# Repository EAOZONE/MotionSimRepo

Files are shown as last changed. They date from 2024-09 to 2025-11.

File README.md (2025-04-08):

# Project Description
This python project is an automation tool to control some hardware with your computer. It uses the `PySide6` library for a graphical user interface (GUI) and the `serial` library to communicate with an Arduino controller which manages the hardware. The CSV file containing required details is read using `Pandas`, a powerful library for data analysis in Python.
## Module Descriptions
The project is split into three different files:
1. **widget.py**: This file is the main application, it creates a GUI using PySide6 which allows user to interact with the application. The GUI comprises of elements including buttons, checkboxes, sliders etc. It leverages `ArdiunoTalk` and `saveFileAsArr` classes to communicate with Arduino and manipulate data respectively. It also includes keyboard event to trigger function via key press.
2. **talkToArduino.py**: This file includes class `ArdiunoTalk` which establishes communication with Arduino and sends angles by writing to serial. It also includes functionality to enable/disable the Arduino operation.
3. **readCSV.py**: This file contains a function to read a CSV file and return its contents as a list of tuples. It uses pandas library to accomplish this.

## Setup & Usage
You can run the project simply by running the `widget.py` file in a python environment that has the `PySide6`, `Pandas`, and `serial` libraries installed. This opens a graphical user interface which can be used to interact with the connected Arduino.
This application assumes that the Arduino is connected to the computer and there exists a CSV file named `test.csv` in the same directory containing the required information in the format needed.
## Functionality
Once enabled by checking the `Enable All` checkbox on the UI, you can then interact with:
- Home button to set all angles to 0.
- The three dials to manually adjust angles.
- A list of predefined named buttons that represent specific sequences of angles, which are read from a CSV file.
- An `E-Stop` button can be used to discontinue execution of any ongoing command.
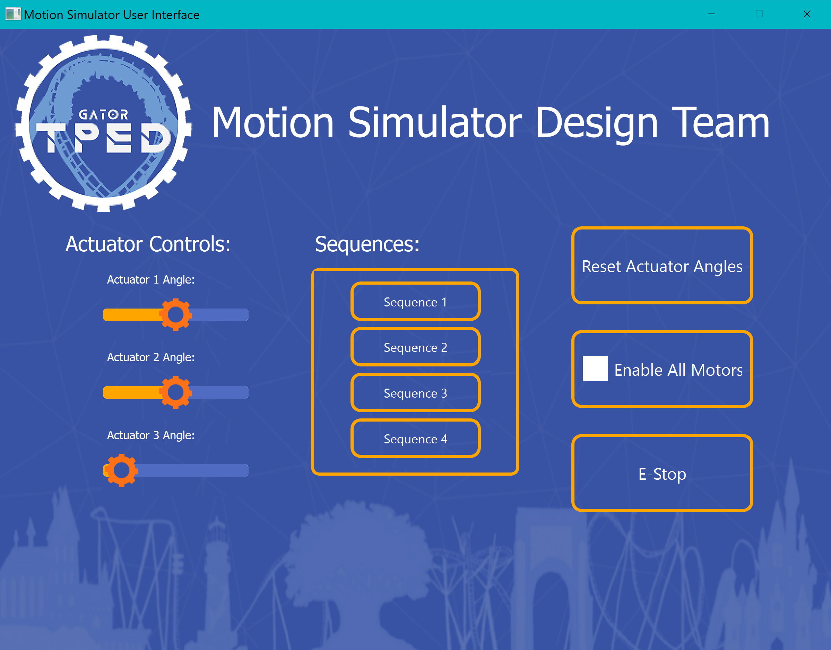
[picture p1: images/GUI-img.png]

This is a very flexible codebase and can be edited according to your individual needs. For further queries & understanding about the code, kindly delve into the files.

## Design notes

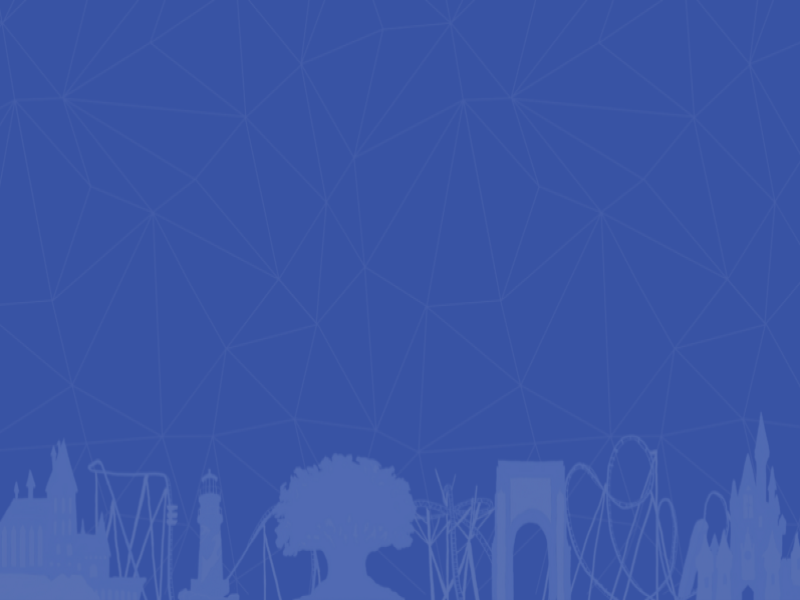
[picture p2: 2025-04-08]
images/background.png

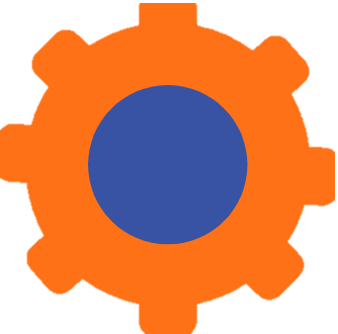
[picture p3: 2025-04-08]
images/gear.png

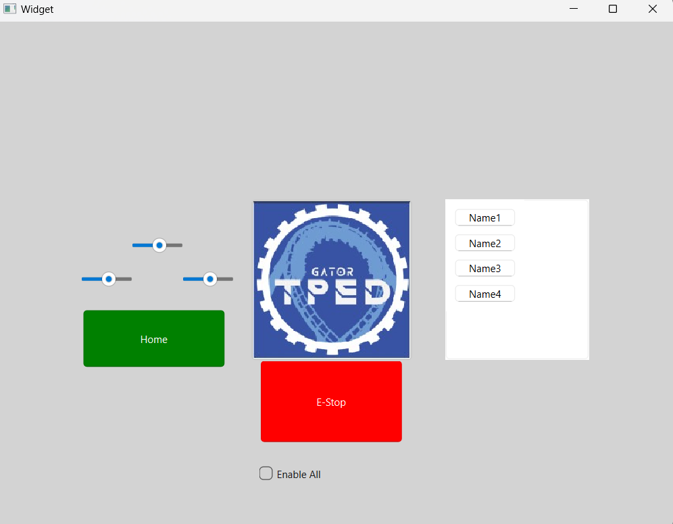
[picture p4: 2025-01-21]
images/img.png

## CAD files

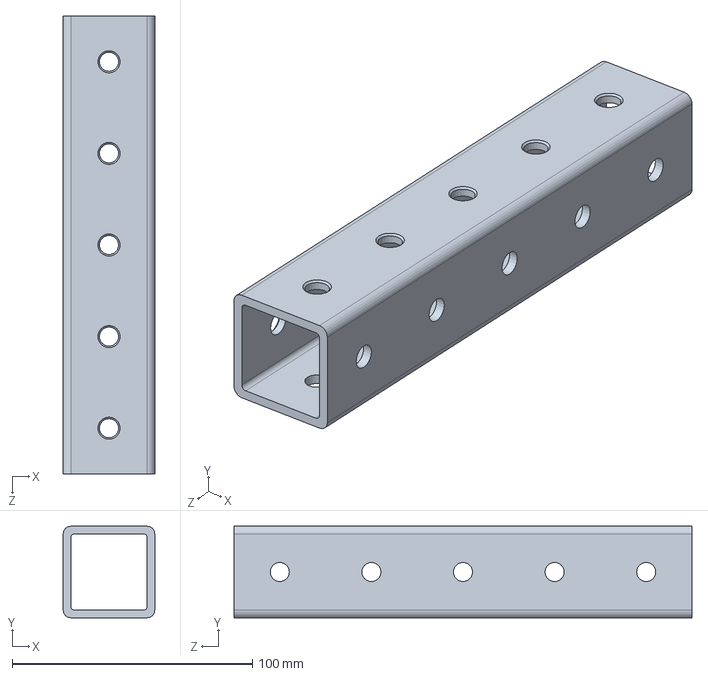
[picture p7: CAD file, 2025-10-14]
SOLIDWORKS/midassembly (1)/9701-7_5-CL.SLDPRT
38.1 x 38.1 x 190.5 mm

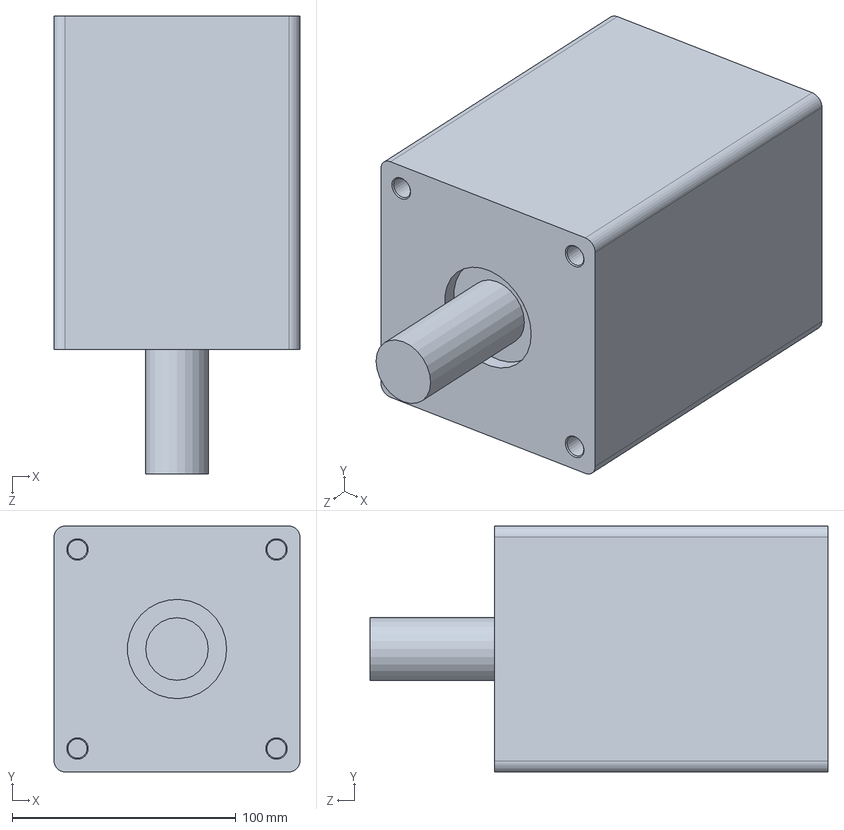
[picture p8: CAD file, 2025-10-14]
SOLIDWORKS/midassembly (1)/Nema 42.SLDPRT
110.0 x 110.0 x 204.6 mm

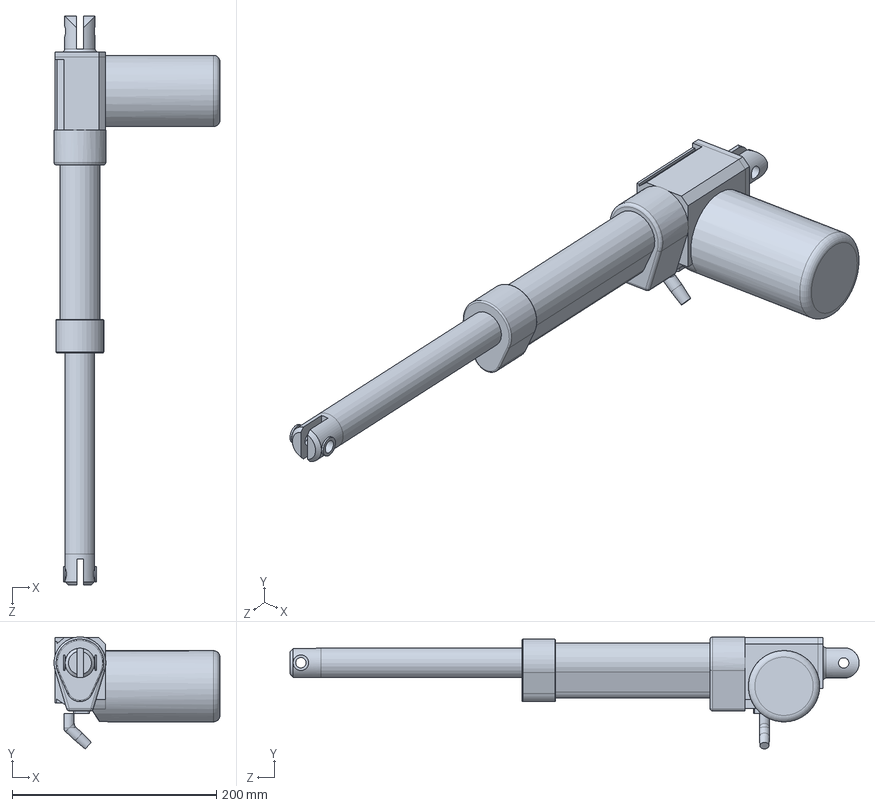
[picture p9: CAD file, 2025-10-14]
SOLIDWORKS/midassembly (1)/PA-04 (4).SLDPRT
162.6 x 109.6 x 557.2 mm

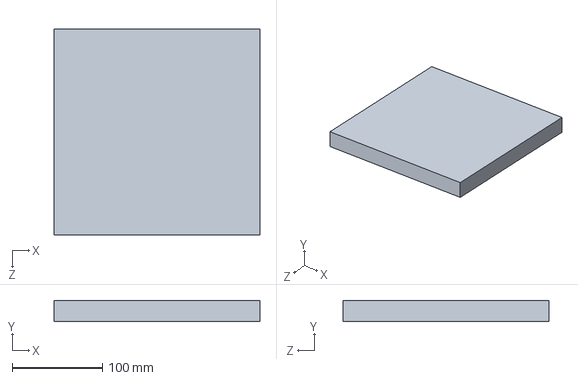
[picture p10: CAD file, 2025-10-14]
SOLIDWORKS/midassembly (1)/wood spacer.SLDPRT
228.6 x 23.6 x 228.6 mm

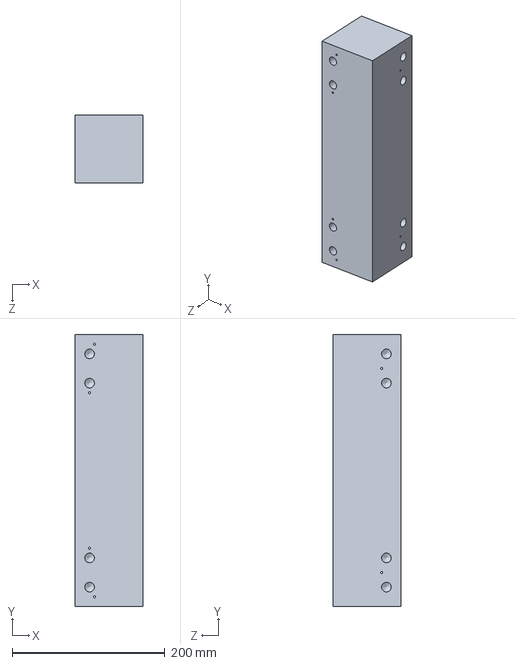
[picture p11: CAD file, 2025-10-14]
SOLIDWORKS/midassembly (1)/2by4legB.SLDPRT
88.9 x 355.6 x 88.9 mm

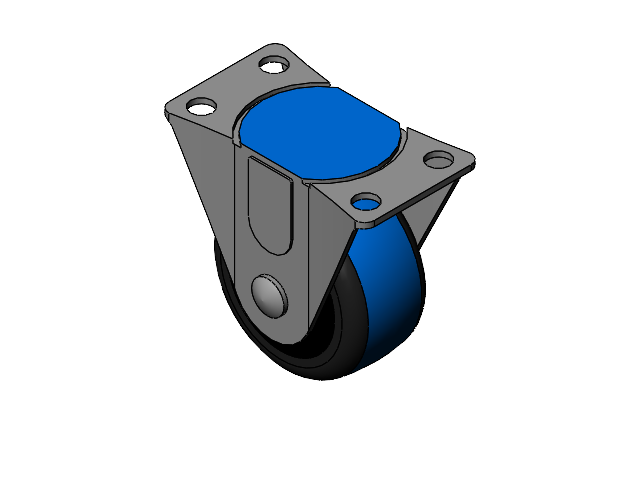
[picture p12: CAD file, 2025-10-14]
SOLIDWORKS/midassembly (1)/30POP20R.sldasm
100-20R_R
21.25-A
21-2x1-T
21-2x1-C

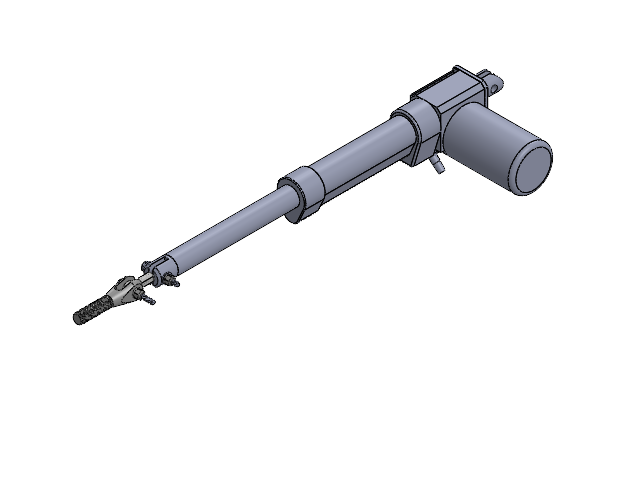
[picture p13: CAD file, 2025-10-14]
SOLIDWORKS/midassembly (1)/ActuatorAssembly.SLDASM
PA-04 (4)
2440K51_High-Strength Fully Threaded Rod End Bolt
2458K321_Lubrication-Free Ball Joint Rod End
90945A760_18-8 Stainless Steel Mil. Spec. Washer x 5
4749T191_Externally Threaded Clevis Rod End
92320A622_18-8 Stainless Steel Unthreaded Spacer x 2
91268A109_High-Strength Grade 8 Steel Hex Head Screw x 2
90630A110_High-Strength Steel Nylon-Insert Locknut (1) x 2
92871A083_18-8 Stainless Steel Unthreaded Spacer x 2

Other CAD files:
SOLIDWORKS/midassembly (1)/Table Top Gear 1.SLDASM
SOLIDWORKS/midassembly (1)/Table Top Gear_ThickTest2.SLDASM
SOLIDWORKS/midassembly (1)/Turntable Gear.SLDASM
SOLIDWORKS/midassembly (1)/Gear.SLDASM
SOLIDWORKS/midassembly (1)/Table Top Gear.SLDASM
SOLIDWORKS/midassembly (1)/Drive Gear 1.SLDASM
SOLIDWORKS/midassembly (1)/Drive Gear.SLDASM
SOLIDWORKS/midassembly (1)/Table Top Gear_ThickTest.SLDASM
SOLIDWORKS/midassembly (1)/Drive Gear_ThickTest.SLDASM
SOLIDWORKS/midassembly (1)/21-2x1-T.sldprt
SOLIDWORKS/midassembly (1)/21-2x1-C.sldprt
SOLIDWORKS/Gear.SLDASM
SOLIDWORKS/Turntable Gear.SLDASM
SOLIDWORKS/midassembly (1)/100-20R_R.sldprt
SOLIDWORKS/midassembly (1)/1544T12_Lubricated Turntable.SLDPRT
SOLIDWORKS/midassembly (1)/21.25-A.sldprt
SOLIDWORKS/midassembly (1)/2440K51_High-Strength Fully Threaded Rod End Bolt.SLDPRT
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

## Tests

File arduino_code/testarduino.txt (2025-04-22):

// Motor control pins
const int enPin  = 8;   // MegaMoto ENABLE pin
const int pwmA   = 9;   // MegaMoto PWMA (forward / extend)
const int pwmB   = 10;  // MegaMoto PWMB (reverse / retract)

// Hall effect sensor pin
const int hallPin = 2;  // Must be an interrupt-capable pin on your Arduino

// Timing and speed parameters
const int extendTime = 5000;  // milliseconds
const int retractTime = 5000;
const int speed = 200;        // PWM duty cycle (0–255)

// Pulse count variable
volatile unsigned long pulseCount = 0;

void setup() {
  // Initialize motor control pins
  pinMode(enPin, OUTPUT);
  pinMode(pwmA, OUTPUT);
  pinMode(pwmB, OUTPUT);
  digitalWrite(enPin, HIGH); // Enable motor driver

  // Initialize hall effect sensor pin
  pinMode(hallPin, INPUT_PULLUP); // Use internal pull-up resistor
  attachInterrupt(digitalPinToInterrupt(hallPin), countPulse, RISING); // Trigger on rising edge

  // Initialize serial communication
  Serial.begin(9600);
}

void loop() {
  // Reset pulse count
  pulseCount = 0;

  // Retract actuator
  analogWrite(pwmA, 0);
  analogWrite(pwmB, speed);
  delay(retractTime);
  analogWrite(pwmB, 0); // Stop motor

  // Output pulse count after retraction
  Serial.print("Retract pulses: ");
  Serial.println(pulseCount);

  delay(1000); // Pause before next movement

  // Reset pulse count
  pulseCount = 0;

  // Extend actuator
  analogWrite(pwmA, speed);
  analogWrite(pwmB, 0);
  delay(extendTime);
  analogWrite(pwmA, 0); // Stop motor

  // Output pulse count after extension
  Serial.print("Extend pulses: ");
  Serial.println(pulseCount);

  delay(1000); // Pause before next cycle
}

// Interrupt Service Routine (ISR) for counting pulses
void countPulse() {
  pulseCount++;
}

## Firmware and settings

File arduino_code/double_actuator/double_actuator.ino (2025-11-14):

// ===================== USER-CONFIGURABLE CONSTANTS =====================
const float MAX_SPEED_IPS = 2.16;   // actuator speed in inches/second at full power
const float STROKE_IN     = 12.0;   // total stroke length in inches

// MegaMoto #1 (Actuator 1)
const int ENABLE1 = 8;
const int FWD1    = 11;   // PWM pin
const int REV1    = 3;    // PWM pin

// MegaMoto #2 (Actuator 2)
const int ENABLE2 = 7;
const int FWD2    = 10;   // PWM pin
const int REV2    = 5;    // PWM pin

// ===================== STATE VARIABLES =====================
float pos1_in = 0.0;  // estimated position of actuator 1 in inches (0 = fully retracted)
float pos2_in = 0.0;  // estimated position of actuator 2 in inches

// ===================== BASIC MOTOR CONTROL HELPERS =====================
void stopActuator1() {
  digitalWrite(ENABLE1, LOW);
  analogWrite(FWD1, 0);
  analogWrite(REV1, 0);
}

void stopActuator2() {
  digitalWrite(ENABLE2, LOW);
  analogWrite(FWD2, 0);
  analogWrite(REV2, 0);
}

void driveActuator1(int direction, int pwm) {
  // direction: +1 = extend (FWD), -1 = retract (REV), 0 = stop
  if (direction == 0 || pwm == 0) {
    stopActuator1();
    return;
  }

  digitalWrite(ENABLE1, HIGH);
  if (direction > 0) {
    // Extend
    analogWrite(REV1, 0);
    analogWrite(FWD1, pwm);
  } else {
    // Retract
    analogWrite(FWD1, 0);
    analogWrite(REV1, pwm);
  }
}

void driveActuator2(int direction, int pwm) {
  // direction: +1 = extend (FWD), -1 = retract (REV), 0 = stop
  if (direction == 0 || pwm == 0) {
    stopActuator2();
    return;
  }

  digitalWrite(ENABLE2, HIGH);
  if (direction > 0) {
    // Extend
    analogWrite(REV2, 0);
    analogWrite(FWD2, pwm);
  } else {
    // Retract
    analogWrite(FWD2, 0);
    analogWrite(REV2, pwm);
  }
}

// ===================== SETUP =====================
void setup() {
  pinMode(ENABLE1, OUTPUT);
  pinMode(FWD1, OUTPUT);
  pinMode(REV1, OUTPUT);

  pinMode(ENABLE2, OUTPUT);
  pinMode(FWD2, OUTPUT);
  pinMode(REV2, OUTPUT);

  stopActuator1();
  stopActuator2();

  Serial.begin(9600);
  Serial.println("System starting...");

  resetActuators();   // <<< run reset here

  Serial.println("Ready for serial commands: pos1,pos2,time");
}
void resetActuators() {
  Serial.println("Resetting actuators (full retract)…");

  // Full reverse, both actuators
  driveActuator1(-1, 255);   // direction -1 = retract
  driveActuator2(-1, 255);

  delay(7000);  // long enough to fully retract (adjust as needed)

  stopActuator1();
  stopActuator2();

  // Set known positions
  pos1_in = 0.0;
  pos2_in = 0.0;

  Serial.println("Reset complete. Both actuators set to 0 inches.");
}
// ===================== MAIN LOOP =====================
void loop() {
  if (Serial.available() > 0) {
    // Parse 3 numbers: pos1, pos2, time
    float target1 = Serial.parseFloat();   // actuator 1 target position (inches)
    float target2 = Serial.parseFloat();   // actuator 2 target position (inches)
    float target3 = Serial.parseFloat();
    float moveTime = Serial.parseFloat();  // move time (seconds)

    // optional: eat the rest of the line
    while (Serial.available() > 0) {
      char c = Serial.read();
      if (c == '\n' || c == '\r') break;
    }

    // Validate move time
    if (moveTime <= 0) {
      Serial.println("Error: time must be > 0");
      return;
    }

    // Constrain positions to stroke range
    target1 = constrain(target1, 0.0, STROKE_IN);
    target2 = constrain(target2, 0.0, STROKE_IN);

    Serial.print("Command received: ");
    Serial.print(target1); Serial.print(" in, ");
    Serial.print(target2); Serial.print(" in, ");
    Serial.print(moveTime); Serial.println(" s");

    moveActuatorsToTargets(target1, target2, moveTime);
  }
}

// ===================== MOTION FUNCTION =====================
void moveActuatorsToTargets(float target1, float target2, float moveTime) {
  // Compute distance to move
  float delta1 = target1 - pos1_in;
  float delta2 = target2 - pos2_in;

  float dist1 = fabs(delta1);
  float dist2 = fabs(delta2);

  // Determine directions
  int dir1 = (delta1 > 0) - (delta1 < 0); // +1, 0, or -1
  int dir2 = (delta2 > 0) - (delta2 < 0);

  // If no movement requested, just stop
  if (dist1 == 0 && dist2 == 0) {
    Serial.println("No movement required.");
    stopActuator1();
    stopActuator2();
    return;
  }

  // Required speeds to reach each target in the given time
  float reqSpeed1 = (moveTime > 0) ? dist1 / moveTime : 0.0; // in/s
  float reqSpeed2 = (moveTime > 0) ? dist2 / moveTime : 0.0; // in/s

  // Convert required speeds to PWM (assuming linear from 0 to MAX_SPEED_IPS)
  // pwm = 255 * (required_speed / max_speed)
  float pwm1f = (MAX_SPEED_IPS > 0) ? (255.0 * reqSpeed1 / MAX_SPEED_IPS) : 0.0;
  float pwm2f = (MAX_SPEED_IPS > 0) ? (255.0 * reqSpeed2 / MAX_SPEED_IPS) : 0.0;

  // Limit PWM to [0,255]
  pwm1f = constrain(pwm1f, 0.0, 255.0);
  pwm2f = constrain(pwm2f, 0.0, 255.0);

  int pwm1 = (int)pwm1f;
  int pwm2 = (int)pwm2f;

  // Check if we’re asking more than the actuator can physically do
  if (reqSpeed1 > MAX_SPEED_IPS || reqSpeed2 > MAX_SPEED_IPS) {
    Serial.println("Warning: requested move is faster than max speed.");
    Serial.println("Actuators will run at max speed and may not reach targets in the given time.");
  }

  // Start motion
  driveActuator1(dir1, pwm1);
  driveActuator2(dir2, pwm2);

  // Block until moveTime has passed (simple version)
  unsigned long ms = (unsigned long)(moveTime * 1000.0);
  delay(ms);

  // Stop both actuators
  stopActuator1();
  stopActuator2();

  // Update our estimated positions
  // If speed was within range, assume we hit the target; otherwise approximate
  if (reqSpeed1 <= MAX_SPEED_IPS) {
    pos1_in = target1;
  } else {
    // moved ~MAX_SPEED_IPS * time in the desired direction
    pos1_in += dir1 * MAX_SPEED_IPS * moveTime;
    pos1_in = constrain(pos1_in, 0.0, STROKE_IN);
  }

  if (reqSpeed2 <= MAX_SPEED_IPS) {
    pos2_in = target2;
  } else {
    pos2_in += dir2 * MAX_SPEED_IPS * moveTime;
    pos2_in = constrain(pos2_in, 0.0, STROKE_IN);
  }

  Serial.print("New estimated positions: A1 = ");
  Serial.print(pos1_in);
  Serial.print(" in, A2 = ");
  Serial.print(pos2_in);
  Serial.println(" in");
}

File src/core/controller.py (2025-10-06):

"""HID-based controller polling using hidapi."""

from __future__ import annotations

import os
import sys
import struct
import time
from dataclasses import dataclass
from typing import Dict, Optional, Tuple

from PySide6.QtCore import QObject, Signal

try:  # optional dependency
    import hid  # type: ignore
except Exception:  # pragma: no cover - keep UI responsive when missing
    hid = None  # type: ignore

try:  # optional Windows dependency
    from inputs import get_gamepad as _inputs_get_gamepad  # type: ignore
    from inputs import UnpluggedError as _inputs_unplugged_error  # type: ignore
except Exception:  # pragma: no cover - optional
    _inputs_get_gamepad = None
    _inputs_unplugged_error = Exception


@dataclass(frozen=True)
class AxisSpec:
    index: int
    size: int = 1  # bytes (1 or 2)
    invert: bool = False


@dataclass(frozen=True)
class ButtonSpec:
    byte: int
    bit: int


@dataclass(frozen=True)
class TriggerSpec:
    axis: Optional[AxisSpec] = None
    button: Optional[ButtonSpec] = None


@dataclass
class HIDLayout:
    axes: Dict[str, AxisSpec]
    triggers: Dict[str, TriggerSpec]
    buttons: Dict[str, ButtonSpec]
    hat_index: Optional[int]

    @classmethod
    def from_report(cls, report: bytes) -> "HIDLayout":
        n = len(report)

        axes: Dict[str, AxisSpec] = {}
        if n >= 2:
            axes["lx"] = AxisSpec(0)
            axes["ly"] = AxisSpec(1, invert=True)
        if n >= 4:
            axes["rx"] = AxisSpec(2)
            axes["ry"] = AxisSpec(3, invert=True)

        hat_index = None
        if n > 4 and report[4] <= 8:
            hat_index = 4

        buttons: Dict[str, ButtonSpec] = {}
        if n > 5:
            buttons.update(
                {
                    "BTN_SOUTH": ButtonSpec(5, 0),
                    "BTN_EAST": ButtonSpec(5, 1),
                    "BTN_WEST": ButtonSpec(5, 2),
                    "BTN_NORTH": ButtonSpec(5, 3),
                }
            )

        triggers: Dict[str, TriggerSpec] = {
            "lt": TriggerSpec(button=ButtonSpec(5, 4) if n > 5 else None),
            "rt": TriggerSpec(button=ButtonSpec(5, 5) if n > 5 else None),
        }

        if n > 7:
            triggers["lt"] = TriggerSpec(axis=AxisSpec(6))
            triggers["rt"] = TriggerSpec(axis=AxisSpec(7))

        return cls(axes=axes, triggers=triggers, buttons=buttons, hat_index=hat_index)


def _normalize_unsigned(raw: int, bits: int) -> float:
    max_val = float((1 << bits) - 1)
    if max_val <= 0:
        return 0.0
    return (raw / max_val) * 2.0 - 1.0


def _apply_deadzone(value: float, dead: float) -> float:
    if abs(value) < dead:
        return 0.0
    return max(-1.0, min(1.0, value))


class ControllerWorker(QObject):
    """Polls a HID game controller and emits motion updates."""

    connected = Signal()
    disconnected = Signal()
    anglesChanged = Signal(float, float, float)  # pitch, roll, yaw
    estopRequested = Signal()
    homeRequested = Signal()
    enableToggle = Signal()
    debugEvent = Signal(str)

    def __init__(self, poll_hz: int = 120, deadzone: float = 0.10, parent: Optional[QObject] = None):
        super().__init__(parent)
        self._running = False
        self._enabled = True
        self._dt = 1.0 / float(max(30, poll_hz))
        self._dead = float(deadzone)
        self._backend = "hid"

        self._device: Optional["hid.Device"] = None
        self._layout: Optional[HIDLayout] = None
        self._connected = False

        self._lx = 0.0
        self._ly = 0.0
        self._rx = 0.0
        self._ry = 0.0
        self._lt = -1.0
        self._rt = -1.0

        self._buttons: Dict[str, int] = {
            "BTN_SOUTH": 0,
            "BTN_EAST": 0,
            "BTN_WEST": 0,
            "BTN_NORTH": 0,
        }

        self._xinput_active = False
        self._last_axes_debug = 0.0
        self._xinput_center: Optional[Tuple[int, int, int, int]] = None
        self._inputs_center: Dict[str, float] = {}
        self._inputs_span: Dict[str, float] = {}

        self._preferred_vendor = _parse_int_env("MOTIONSIM_HID_VENDOR")
        self._preferred_product = _parse_int_env("MOTIONSIM_HID_PRODUCT")
        self._preferred_path = os.getenv("MOTIONSIM_HID_PATH")

    # ===== lifecycle =====================================================
    def start(self) -> None:
        self._running = True
        self._backend = self._select_backend()
        self.debugEvent.emit(f"Controller backend: {self._backend}")

        if self._backend == "inputs":
            self._inputs_loop()
        else:
            self._hid_loop()

    def stop(self) -> None:
        self._running = False

    def set_enabled(self, on: bool) -> None:
        self._enabled = bool(on)

    def toggle_enabled(self) -> None:
        self._enabled = not self._enabled

    # ===== helpers =======================================================
    def _select_backend(self) -> str:
        if sys.platform.startswith("win"):
            if _inputs_get_gamepad is not None:
                return "inputs"
            self.debugEvent.emit("inputs library unavailable; falling back to HID backend")
        return "hid"

    def _inputs_loop(self) -> None:
        last_emit = 0.0
        self._set_connected(False)

        while self._running:
            try:
                events = _inputs_get_gamepad()  # type: ignore[misc]
            except _inputs_unplugged_error:
                self._set_connected(False)
                time.sleep(0.5)
                continue
            except Exception as exc:  # pragma: no cover - defensive
                self.debugEvent.emit(f"inputs read failed: {exc}")
                self._set_connected(False)
                time.sleep(0.5)
                continue

            self._set_connected(True)

            for ev in events:
                code = getattr(ev, "code", None)
                etype = getattr(ev, "ev_type", None)
                state = getattr(ev, "state", None)
                if code is None or etype is None or state is None:
                    continue

                if etype == "Sync":
                    continue
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

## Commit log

2024-09-17 actuator3 dial
2024-09-19 Switches to horizontal sliders
2024-09-24 UI sends data to Arduino
2024-09-24 arduino code
2025-01-21 makes .csv talk to arduino (sort of)
2025-01-28 Enable and disable buttons to stop two movements happening at same time
    [test.csv]
2025-02-05 fix for servos resetting to zero
2025-02-11 clean up arduino code
2025-02-26 arduino code for actuator
2025-04-02 Project Structure Reformat
    [test.csv]
2025-04-29 Arduino Actuator Code Working
    [test.csv]
2025-04-29 test.csv simple example to test sequence
    [test.csv]
2025-04-29 adds ResetToZero before going to midpoint
    [double_actuator.ino]
2025-09-16 gear image
2025-09-23 uncomments arduino and csv
2025-09-23 adds qdial for final actuator
2025-10-06 Moves everything out of restructured into src
    [Name1.csv, test.csv]
2025-10-07 Implements way to append to sequences
    [Name1.csv]
2025-10-07 Sets up way for dt to be set for each line and estop to actually stop stuff
    [Name1.csv]
2025-10-13 added gear and turntable
    [Gear.SLDASM, Turntable Gear.SLDASM]
2025-10-14 Added updated final assembly
    [100-20R_R.sldprt, 21-2x1-C.sldprt, 21-2x1-T.sldprt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]
2025-10-14 missing parts
    [1544T12_Lubricated Turntable.SLDPRT, 9140T106_Multipurpose 6061 Aluminum Bar.SLDPRT]
2025-11-14 New arduino code for now
